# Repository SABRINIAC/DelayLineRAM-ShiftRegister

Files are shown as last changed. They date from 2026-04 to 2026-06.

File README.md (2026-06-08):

# Delay Line RAM (Or technically SAM)

This project is the RAM for a '60s inspired computer im making called the SABRINIAC. It is delay line ram, which means all of the bits shift in a circular loop. To read from the memory you wait for the right bits to come by (You can find out the current address its on by the 2nd pcb in this project, the address counter) and then take in those bits. to write its similar but you set the data in to the bit you want to write, and then set write enable high when the bit you want to write passes by. It will write the data in bit instead of passing the bit around again.

I made this project because I saw a video of someone programming the UNIVAC to run a minecraft server. And also, ive built digital CPUs and now I've wanted to try my hand and building one in real life, along with the components to make it work!

This build is meant to have 8 of the RAM modules and 1 address counter module, as then you can run all the ram in parallel and have it cycle 1 byte every clock tick. Allowing 256 Bytes of memory and simpler access, instead of reading data in serially.

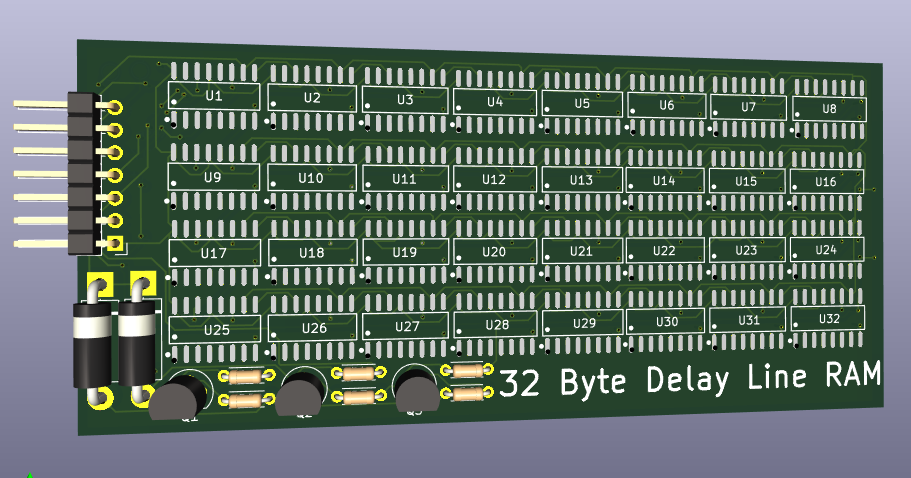
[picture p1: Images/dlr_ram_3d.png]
Delay Line RAM PCB

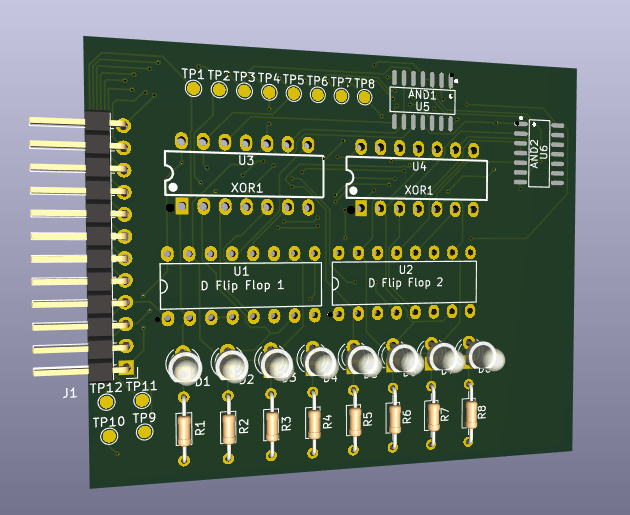
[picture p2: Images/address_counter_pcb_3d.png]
Address Counter PCB


| Part Name | Count |
|---|---|
| PCB - Address counter | 1 |
| PCB - Delay Line RAM | 8 |
| 4x1 Female Pin Headers | 17 |
| 74HC08DS Quad AND Gate | 2 |
| 74HC86N Quad XOR Gate | 2 |
| 74LS175N Quad D Flip Flop | 2 |
| 2x1 Right Angle Male Pin Headers | 34 |
| 1KΩ Resistor | 64 |
| 2N2222A NPN Transistor | 24 |
| 74HC595 8Bit SIPO Shift Registers | 256 |

Note there is no LEDs or resistors for the address counter PCB, I intend to leave it unpopulated unless I need to debug. It will work just fine without those parts

# Built Modules




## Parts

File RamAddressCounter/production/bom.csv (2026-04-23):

Designator | Footprint | Quantity | Value | LCSC Part #
D1, D2, D3, D4, D5, D6, D7, D8 | LED_D3.0mm_Clear | 8 | LED
J1 | PinHeader_1x12_P2.54mm_Horizontal | 1 | IO Connector Pins
R1, R2, R3, R4, R5, R6, R7, R8 | R_Axial_DIN0204_L3.6mm_D1.6mm_P7.62mm_Horizontal | 8 | R
TP1, TP10, TP11, TP12, TP2, TP3, TP4, TP5, TP6, TP7, TP8, TP9 | TestPoint_Pad_D1.5mm | 12 | TestPoint
U1 | DIP-16_L19.3-W6.4-P2.54-LS7.6-BL | 1 | D Flip Flop 1
U2 | DIP-16_L19.3-W6.4-P2.54-LS7.6-BL | 1 | D Flip Flop 2
U3, U4 | PDIP-14_L19.3-W6.5-P2.54-LS7.6-BL | 2 | XOR1
U5 | SOP-14_L8.8-W3.9-P1.27-LS6.0-BL | 1 | AND1
U6 | SOP-14_L8.8-W3.9-P1.27-LS6.0-BL | 1 | AND2

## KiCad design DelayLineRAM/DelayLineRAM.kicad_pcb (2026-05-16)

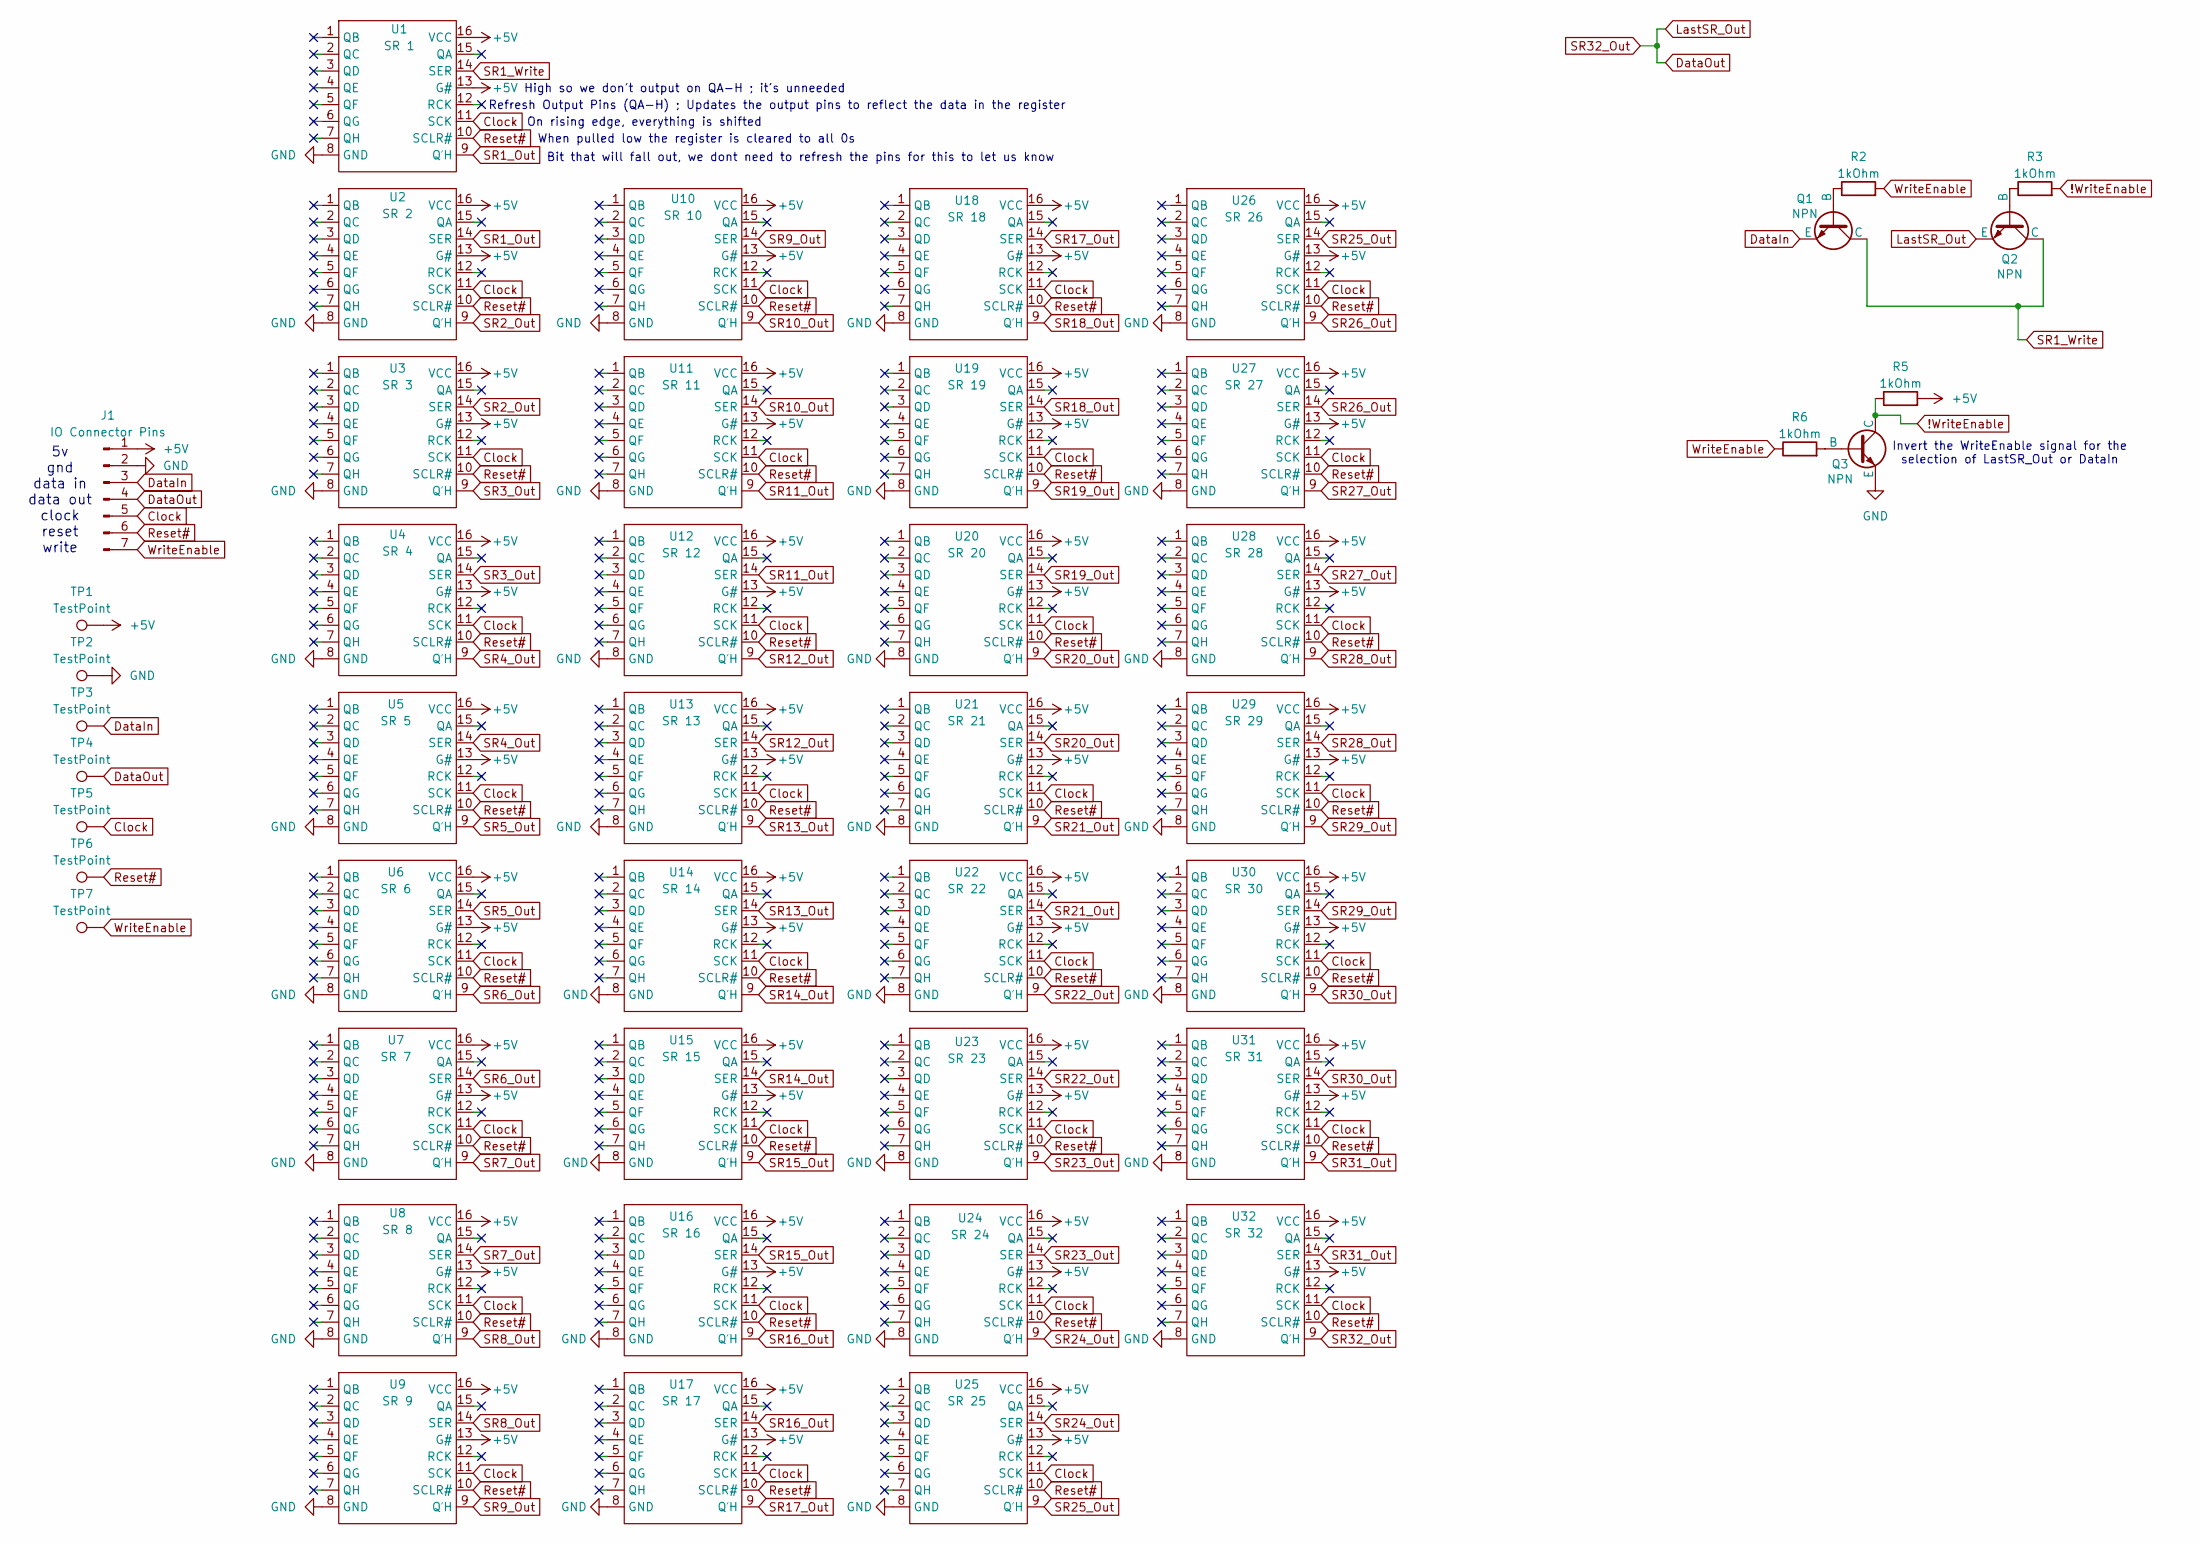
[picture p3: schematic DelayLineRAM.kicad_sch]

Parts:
J1: IO Connector Pins; PinHeader_1x07_P2.54mm_Horizontal
Q1, Q2, Q3: NPN; TO-92
R2, R3, R5, R6: 1kOhm; R_Axial_DIN0204_L3.6mm_D1.6mm_P5.08mm_Horizontal
TP1, TP2, TP3, TP4, TP5, TP6, TP7: TestPoint; TestPoint_Pad_D1.5mm
U1: SR 1; SOP-16_L9.9-W3.9-P1.27-LS6.0-BL; Manufacturer Part 74HC595DRG; LCSC Part Name 74系列 逻辑芯片
U2: SR 2; SOP-16_L9.9-W3.9-P1.27-LS6.0-BL; Manufacturer Part 74HC595DRG; LCSC Part Name 74系列 逻辑芯片
U3: SR 3; SOP-16_L9.9-W3.9-P1.27-LS6.0-BL; Manufacturer Part 74HC595DRG; LCSC Part Name 74系列 逻辑芯片
U4: SR 4; SOP-16_L9.9-W3.9-P1.27-LS6.0-BL; Manufacturer Part 74HC595DRG; LCSC Part Name 74系列 逻辑芯片
U5: SR 5; SOP-16_L9.9-W3.9-P1.27-LS6.0-BL; Manufacturer Part 74HC595DRG; LCSC Part Name 74系列 逻辑芯片
U6: SR 6; SOP-16_L9.9-W3.9-P1.27-LS6.0-BL; Manufacturer Part 74HC595DRG; LCSC Part Name 74系列 逻辑芯片
U7: SR 7; SOP-16_L9.9-W3.9-P1.27-LS6.0-BL; Manufacturer Part 74HC595DRG; LCSC Part Name 74系列 逻辑芯片
U8: SR 8; SOP-16_L9.9-W3.9-P1.27-LS6.0-BL; Manufacturer Part 74HC595DRG; LCSC Part Name 74系列 逻辑芯片
U9: SR 9; SOP-16_L9.9-W3.9-P1.27-LS6.0-BL; Manufacturer Part 74HC595DRG; LCSC Part Name 74系列 逻辑芯片
U10: SR 10; SOP-16_L9.9-W3.9-P1.27-LS6.0-BL; Manufacturer Part 74HC595DRG; LCSC Part Name 74系列 逻辑芯片
U11: SR 11; SOP-16_L9.9-W3.9-P1.27-LS6.0-BL; Manufacturer Part 74HC595DRG; LCSC Part Name 74系列 逻辑芯片
U12: SR 12; SOP-16_L9.9-W3.9-P1.27-LS6.0-BL; Manufacturer Part 74HC595DRG; LCSC Part Name 74系列 逻辑芯片
U13: SR 13; SOP-16_L9.9-W3.9-P1.27-LS6.0-BL; Manufacturer Part 74HC595DRG; LCSC Part Name 74系列 逻辑芯片
U14: SR 14; SOP-16_L9.9-W3.9-P1.27-LS6.0-BL; Manufacturer Part 74HC595DRG; LCSC Part Name 74系列 逻辑芯片
U15: SR 15; SOP-16_L9.9-W3.9-P1.27-LS6.0-BL; Manufacturer Part 74HC595DRG; LCSC Part Name 74系列 逻辑芯片
U16: SR 16; SOP-16_L9.9-W3.9-P1.27-LS6.0-BL; Manufacturer Part 74HC595DRG; LCSC Part Name 74系列 逻辑芯片
U17: SR 17; SOP-16_L9.9-W3.9-P1.27-LS6.0-BL; Manufacturer Part 74HC595DRG; LCSC Part Name 74系列 逻辑芯片
U18: SR 18; SOP-16_L9.9-W3.9-P1.27-LS6.0-BL; Manufacturer Part 74HC595DRG; LCSC Part Name 74系列 逻辑芯片
U19: SR 19; SOP-16_L9.9-W3.9-P1.27-LS6.0-BL; Manufacturer Part 74HC595DRG; LCSC Part Name 74系列 逻辑芯片
U20: SR 20; SOP-16_L9.9-W3.9-P1.27-LS6.0-BL; Manufacturer Part 74HC595DRG; LCSC Part Name 74系列 逻辑芯片
U21: SR 21; SOP-16_L9.9-W3.9-P1.27-LS6.0-BL; Manufacturer Part 74HC595DRG; LCSC Part Name 74系列 逻辑芯片
U22: SR 22; SOP-16_L9.9-W3.9-P1.27-LS6.0-BL; Manufacturer Part 74HC595DRG; LCSC Part Name 74系列 逻辑芯片
U23: SR 23; SOP-16_L9.9-W3.9-P1.27-LS6.0-BL; Manufacturer Part 74HC595DRG; LCSC Part Name 74系列 逻辑芯片
U24: SR 24; SOP-16_L9.9-W3.9-P1.27-LS6.0-BL; Manufacturer Part 74HC595DRG; LCSC Part Name 74系列 逻辑芯片
U25: SR 25; SOP-16_L9.9-W3.9-P1.27-LS6.0-BL; Manufacturer Part 74HC595DRG; LCSC Part Name 74系列 逻辑芯片
U26: SR 26; SOP-16_L9.9-W3.9-P1.27-LS6.0-BL; Manufacturer Part 74HC595DRG; LCSC Part Name 74系列 逻辑芯片
U27: SR 27; SOP-16_L9.9-W3.9-P1.27-LS6.0-BL; Manufacturer Part 74HC595DRG; LCSC Part Name 74系列 逻辑芯片
U28: SR 28; SOP-16_L9.9-W3.9-P1.27-LS6.0-BL; Manufacturer Part 74HC595DRG; LCSC Part Name 74系列 逻辑芯片
U29: SR 29; SOP-16_L9.9-W3.9-P1.27-LS6.0-BL; Manufacturer Part 74HC595DRG; LCSC Part Name 74系列 逻辑芯片
U30: SR 30; SOP-16_L9.9-W3.9-P1.27-LS6.0-BL; Manufacturer Part 74HC595DRG; LCSC Part Name 74系列 逻辑芯片
U31: SR 31; SOP-16_L9.9-W3.9-P1.27-LS6.0-BL; Manufacturer Part 74HC595DRG; LCSC Part Name 74系列 逻辑芯片
U32: SR 32; SOP-16_L9.9-W3.9-P1.27-LS6.0-BL; Manufacturer Part 74HC595DRG; LCSC Part Name 74系列 逻辑芯片

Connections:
!WriteEnable: Q3.1 (C), R3.2, R5.1
+5V: J1.1, R5.2, TP1.1, U1.13 (G#), U1.16 (VCC), U2.13 (G#), U2.16 (VCC), U3.13 (G#), U3.16 (VCC), U4.13 (G#), U4.16 (VCC), U5.13 (G#), U5.16 (VCC), U6.13 (G#), U6.16 (VCC), U7.13 (G#), U7.16 (VCC), U8.13 (G#), U8.16 (VCC), U9.13 (G#), U9.16 (VCC), U10.13 (G#), U10.16 (VCC), U11.13 (G#), U11.16 (VCC), U12.13 (G#), U12.16 (VCC), U13.13 (G#), U13.16 (VCC), U14.13 (G#), U14.16 (VCC), U15.13 (G#), U15.16 (VCC), U16.13 (G#), U16.16 (VCC), U17.13 (G#), U17.16 (VCC), U18.13 (G#), U18.16 (VCC), U19.13 (G#), U19.16 (VCC), U20.13 (G#), U20.16 (VCC), U21.13 (G#), U21.16 (VCC), U22.13 (G#), U22.16 (VCC), U23.13 (G#), U23.16 (VCC), U24.13 (G#), U24.16 (VCC), U25.13 (G#), U25.16 (VCC), U26.13 (G#), U26.16 (VCC), U27.13 (G#), U27.16 (VCC), U28.13 (G#), U28.16 (VCC), U29.13 (G#), U29.16 (VCC), U30.13 (G#), U30.16 (VCC), U31.13 (G#), U31.16 (VCC), U32.13 (G#), U32.16 (VCC)
Clock: J1.5, TP5.1, U1.11 (SCK), U2.11 (SCK), U3.11 (SCK), U4.11 (SCK), U5.11 (SCK), U6.11 (SCK), U7.11 (SCK), U8.11 (SCK), U9.11 (SCK), U10.11 (SCK), U11.11 (SCK), U12.11 (SCK), U13.11 (SCK), U14.11 (SCK), U15.11 (SCK), U16.11 (SCK), U17.11 (SCK), U18.11 (SCK), U19.11 (SCK), U20.11 (SCK), U21.11 (SCK), U22.11 (SCK), U23.11 (SCK), U24.11 (SCK), U25.11 (SCK), U26.11 (SCK), U27.11 (SCK), U28.11 (SCK), U29.11 (SCK), U30.11 (SCK), U31.11 (SCK), U32.11 (SCK)
DataIn: J1.3, Q1.3 (E), TP3.1
DataOut: J1.4, Q2.3 (E), TP4.1, U32.9 (Q′H)
GND: J1.2, Q3.3 (E), TP2.1, U1.8 (GND), U2.8 (GND), U3.8 (GND), U4.8 (GND), U5.8 (GND), U6.8 (GND), U7.8 (GND), U8.8 (GND), U9.8 (GND), U10.8 (GND), U11.8 (GND), U12.8 (GND), U13.8 (GND), U14.8 (GND), U15.8 (GND), U16.8 (GND), U17.8 (GND), U18.8 (GND), U19.8 (GND), U20.8 (GND), U21.8 (GND), U22.8 (GND), U23.8 (GND), U24.8 (GND), U25.8 (GND), U26.8 (GND), U27.8 (GND), U28.8 (GND), U29.8 (GND), U30.8 (GND), U31.8 (GND), U32.8 (GND)
unnamed: Q1.2 (B), R2.1
unnamed: Q2.2 (B), R3.1
unnamed: Q3.2 (B), R6.2
Reset#: J1.6, TP6.1, U1.10 (SCLR#), U2.10 (SCLR#), U3.10 (SCLR#), U4.10 (SCLR#), U5.10 (SCLR#), U6.10 (SCLR#), U7.10 (SCLR#), U8.10 (SCLR#), U9.10 (SCLR#), U10.10 (SCLR#), U11.10 (SCLR#), U12.10 (SCLR#), U13.10 (SCLR#), U14.10 (SCLR#), U15.10 (SCLR#), U16.10 (SCLR#), U17.10 (SCLR#), U18.10 (SCLR#), U19.10 (SCLR#), U20.10 (SCLR#), U21.10 (SCLR#), U22.10 (SCLR#), U23.10 (SCLR#), U24.10 (SCLR#), U25.10 (SCLR#), U26.10 (SCLR#), U27.10 (SCLR#), U28.10 (SCLR#), U29.10 (SCLR#), U30.10 (SCLR#), U31.10 (SCLR#), U32.10 (SCLR#)
SR1_Out: U1.9 (Q′H), U2.14 (SER)
SR1_Write: Q1.1 (C), Q2.1 (C), U1.14 (SER)
SR2_Out: U2.9 (Q′H), U3.14 (SER)
SR3_Out: U3.9 (Q′H), U4.14 (SER)
SR4_Out: U4.9 (Q′H), U5.14 (SER)
SR5_Out: U5.9 (Q′H), U6.14 (SER)
SR6_Out: U6.9 (Q′H), U7.14 (SER)
SR7_Out: U7.9 (Q′H), U8.14 (SER)
SR8_Out: U8.9 (Q′H), U9.14 (SER)
SR9_Out: U9.9 (Q′H), U10.14 (SER)
SR10_Out: U10.9 (Q′H), U11.14 (SER)
SR11_Out: U11.9 (Q′H), U12.14 (SER)
SR12_Out: U12.9 (Q′H), U13.14 (SER)
SR13_Out: U13.9 (Q′H), U14.14 (SER)
SR14_Out: U14.9 (Q′H), U15.14 (SER)
SR15_Out: U15.9 (Q′H), U16.14 (SER)
SR16_Out: U16.9 (Q′H), U17.14 (SER)
SR17_Out: U17.9 (Q′H), U18.14 (SER)
SR18_Out: U18.9 (Q′H), U19.14 (SER)
SR19_Out: U19.9 (Q′H), U20.14 (SER)
SR20_Out: U20.9 (Q′H), U21.14 (SER)
SR21_Out: U21.9 (Q′H), U22.14 (SER)
SR22_Out: U22.9 (Q′H), U23.14 (SER)
SR23_Out: U23.9 (Q′H), U24.14 (SER)
SR24_Out: U24.9 (Q′H), U25.14 (SER)
SR25_Out: U25.9 (Q′H), U26.14 (SER)
SR26_Out: U26.9 (Q′H), U27.14 (SER)
SR27_Out: U27.9 (Q′H), U28.14 (SER)
SR28_Out: U28.9 (Q′H), U29.14 (SER)
SR29_Out: U29.9 (Q′H), U30.14 (SER)
SR30_Out: U30.9 (Q′H), U31.14 (SER)
SR31_Out: U31.9 (Q′H), U32.14 (SER)
WriteEnable: J1.7, R2.2, R6.1, TP7.1

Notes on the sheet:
Bit that will fall out, we dont need to refresh the pins for this to let us know
5v gnd data in data out clock reset write
High so we don't output on QA-H ; it's unneeded
On rising edge, everything is shifted
When pulled low the register is cleared to all 0s
Invert the WriteEnable signal for the selection of LastSR_Out or DataIn
Refresh Output Pins (QA-H) ; Updates the output pins to reflect the data in the register

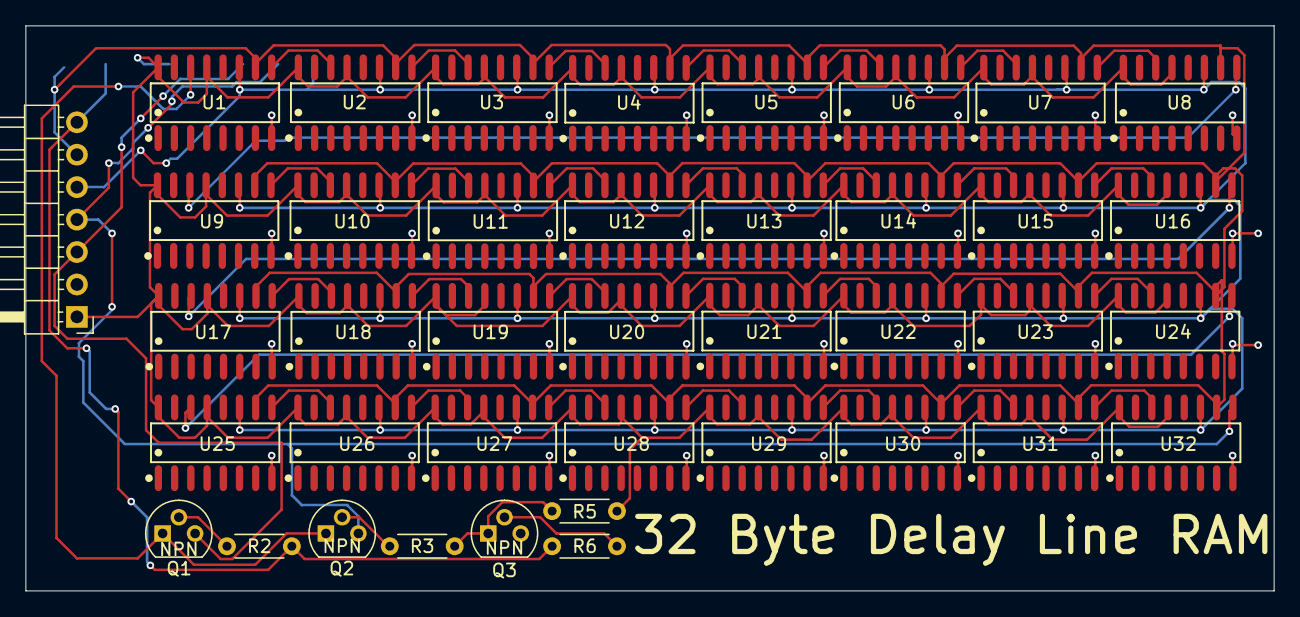
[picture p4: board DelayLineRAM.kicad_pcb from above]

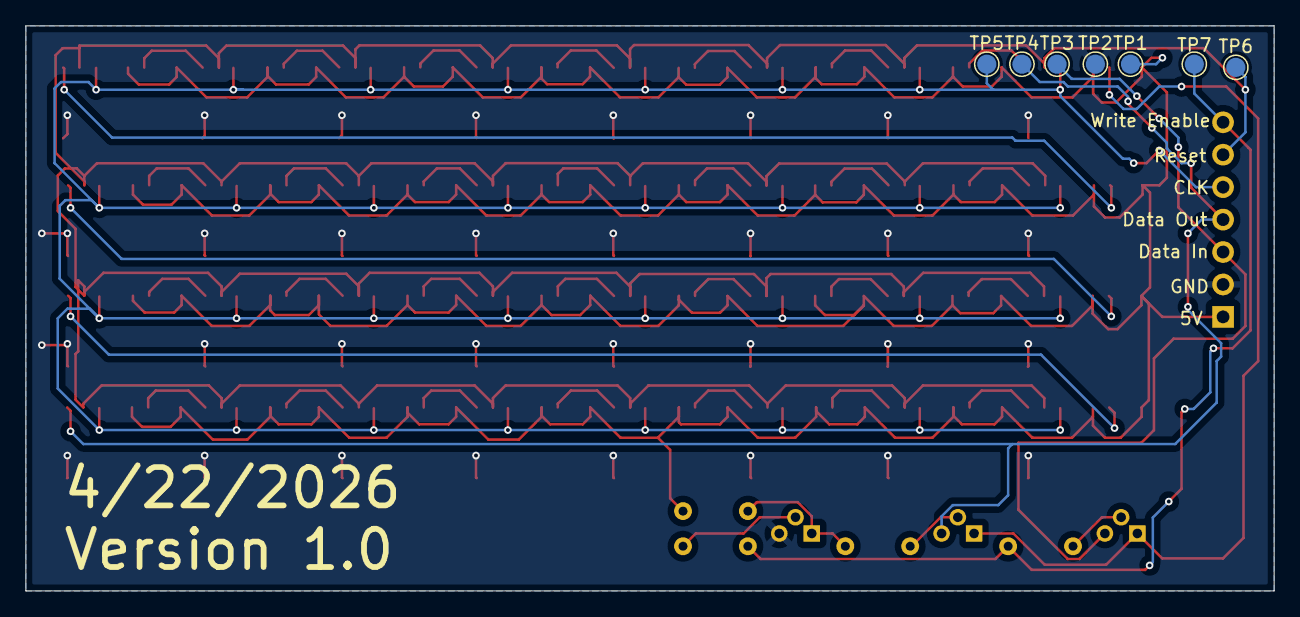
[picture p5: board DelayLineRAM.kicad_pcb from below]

Board: 2 copper layers, 97.8 x 44.2 mm, 47 parts (7 on the bottom side), 43 nets.

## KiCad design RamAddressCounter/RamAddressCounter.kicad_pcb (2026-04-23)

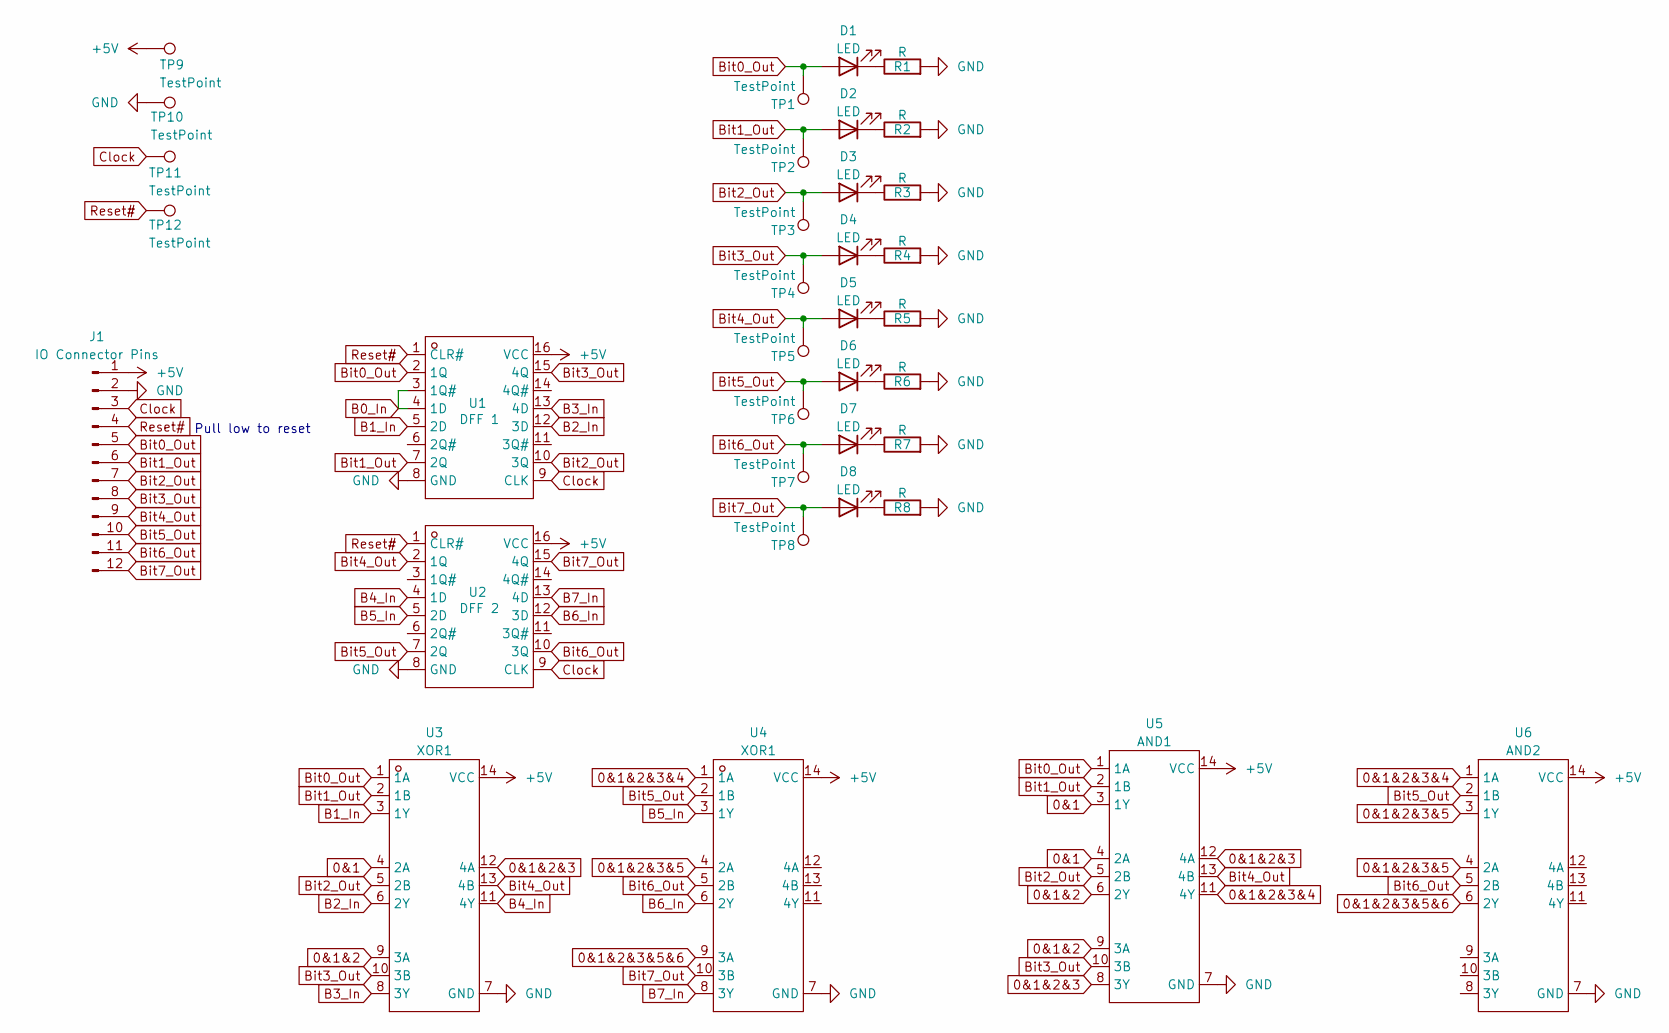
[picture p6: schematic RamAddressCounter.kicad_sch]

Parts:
D1, D2, D3, D4, D5, D6, D7, D8: LED; LED_D3.0mm_Clear
J1: IO Connector Pins; PinHeader_1x12_P2.54mm_Horizontal
R1, R2, R3, R4, R5, R6, R7, R8: R; R_Axial_DIN0204_L3.6mm_D1.6mm_P7.62mm_Horizontal
TP1, TP2, TP3, TP4, TP5, TP6, TP7, TP8, TP9, TP10, TP11, TP12: TestPoint; TestPoint_Pad_D1.5mm
U1: DFF 1; DIP-16_L19.3-W6.4-P2.54-LS7.6-BL; Manufacturer Part SN74LS175N; LCSC Part Name SN74LS175N
U2: DFF 2; DIP-16_L19.3-W6.4-P2.54-LS7.6-BL; Manufacturer Part SN74LS175N; LCSC Part Name SN74LS175N
U3, U4: XOR1; PDIP-14_L19.3-W6.5-P2.54-LS7.6-BL; Manufacturer Part SN74HC86N(LX); LCSC Part Name 集成电路
U5: AND1; SOP-14_L8.8-W3.9-P1.27-LS6.0-BL; Manufacturer Part SN74HC08DS; LCSC Part Name 四2输入与门
U6: AND2; SOP-14_L8.8-W3.9-P1.27-LS6.0-BL; Manufacturer Part SN74HC08DS; LCSC Part Name 四2输入与门

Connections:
0&1: U3.4 (2A), U5.3 (1Y), U5.4 (2A)
0&1&2: U3.9 (3A), U5.6 (2Y), U5.9 (3A)
0&1&2&3: U3.12 (4A), U5.8 (3Y), U5.12 (4A)
0&1&2&3&4: U4.1 (1A), U5.11 (4Y), U6.1 (1A)
0&1&2&3&5: U4.4 (2A), U6.3 (1Y), U6.4 (2A)
0&1&2&3&5&6: U4.9 (3A), U6.6 (2Y)
+5V: J1.1, TP9.1, U1.16 (VCC), U2.16 (VCC), U3.14 (VCC), U4.14 (VCC), U5.14 (VCC), U6.14 (VCC)
B0_In: U1.3 (1Q#), U1.4 (1D)
B1_In: U1.5 (2D), U3.3 (1Y)
B2_In: U1.12 (3D), U3.6 (2Y)
B3_In: U1.13 (4D), U3.8 (3Y)
B4_In: U2.4 (1D), U3.11 (4Y)
B5_In: U2.5 (2D), U4.3 (1Y)
B6_In: U2.12 (3D), U4.6 (2Y)
B7_In: U2.13 (4D), U4.8 (3Y)
Bit0_Out: D1.2 (A), J1.5, TP1.1, U1.2 (1Q), U3.1 (1A), U5.1 (1A)
Bit1_Out: D2.2 (A), J1.6, TP2.1, U1.7 (2Q), U3.2 (1B), U5.2 (1B)
Bit2_Out: D3.2 (A), J1.7, TP3.1, U1.10 (3Q), U3.5 (2B), U5.5 (2B)
Bit3_Out: D4.2 (A), J1.8, TP4.1, U1.15 (4Q), U3.10 (3B), U5.10 (3B)
Bit4_Out: D5.2 (A), J1.9, TP5.1, U2.2 (1Q), U3.13 (4B), U5.13 (4B)
Bit5_Out: D6.2 (A), J1.10, TP6.1, U2.7 (2Q), U4.2 (1B), U6.2 (1B)
Bit6_Out: D7.2 (A), J1.11, TP7.1, U2.10 (3Q), U4.5 (2B), U6.5 (2B)
Bit7_Out: D8.2 (A), J1.12, TP8.1, U2.15 (4Q), U4.10 (3B)
Clock: J1.3, TP11.1, U1.9 (CLK), U2.9 (CLK)
GND: J1.2, R1.2, R2.2, R3.2, R4.2, R5.2, R6.2, R7.2, R8.2, TP10.1, U1.8 (GND), U2.8 (GND), U3.7 (GND), U4.7 (GND), U5.7 (GND), U6.7 (GND)
unnamed: D1.1 (K), R1.1
unnamed: D2.1 (K), R2.1
unnamed: D3.1 (K), R3.1
unnamed: D4.1 (K), R4.1
unnamed: D5.1 (K), R5.1
unnamed: D6.1 (K), R6.1
unnamed: D7.1 (K), R7.1
unnamed: D8.1 (K), R8.1
Reset#: J1.4, TP12.1, U1.1 (CLR#), U2.1 (CLR#)

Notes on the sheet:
Pull low to reset

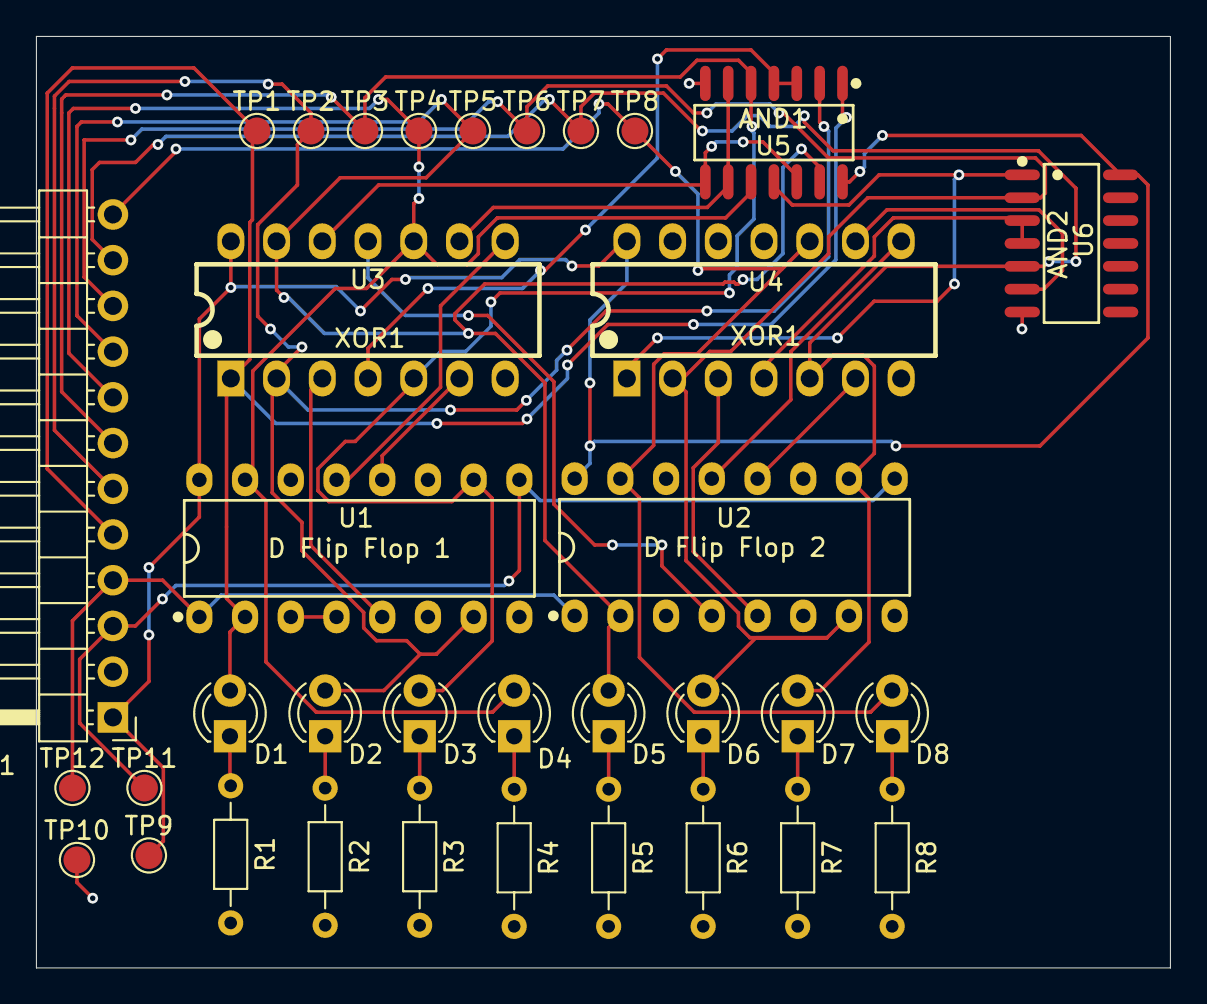
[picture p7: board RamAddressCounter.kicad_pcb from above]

Board: 2 copper layers, 63.0 x 51.8 mm, 35 parts (0 on the bottom side), 34 nets.

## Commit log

2026-04-22 KiCad PCB has been worked on
    [DelayLineRAM.kicad_pcb, DelayLineRAM.kicad_sch, bom.csv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]
2026-04-23 Finished the Address Counter PCB
    [DelayLineRAM.kicad_pcb, DelayLineRAM.kicad_sch, RamAddressCounter.kicad_pcb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]
2026-04-23 Created fab files for the address counter
    [bom.csv, designators.csv, positions.csv]
2026-04-23 removed old fab files for the dlr
    [bom.csv, designators.csv, positions.csv]
2026-04-23 changed ram connector to pin headers and created fab data for the delay line ram
    [DelayLineRAM.kicad_pcb, DelayLineRAM.kicad_sch, bom.csv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]
2026-04-23 idk kicad changed some zip files ig. backups?
2026-04-23 remove old fab files for DLR so i can update the mux line selection circuit
    [DelayLineRAM.kicad_sch, bom.csv, designators.csv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]
2026-04-23 Fixed the MUX for which data line to use when recirculating bits. Created the new FAB files for that too
    [DelayLineRAM.kicad_pcb, bom.csv, designators.csv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]
2026-04-23 Uploaded an image of the completed ram pcb
2026-04-23 Fixed a count in the BOM and clarified why some components are "missing"
2026-05-16 fixed the circuit in kicad for the schem and pcb
    [DelayLineRAM.kicad_pcb, DelayLineRAM.kicad_sch]
2026-05-16 ge3nerated gerbers
    [bom.csv, designators.csv, positions.csv]
